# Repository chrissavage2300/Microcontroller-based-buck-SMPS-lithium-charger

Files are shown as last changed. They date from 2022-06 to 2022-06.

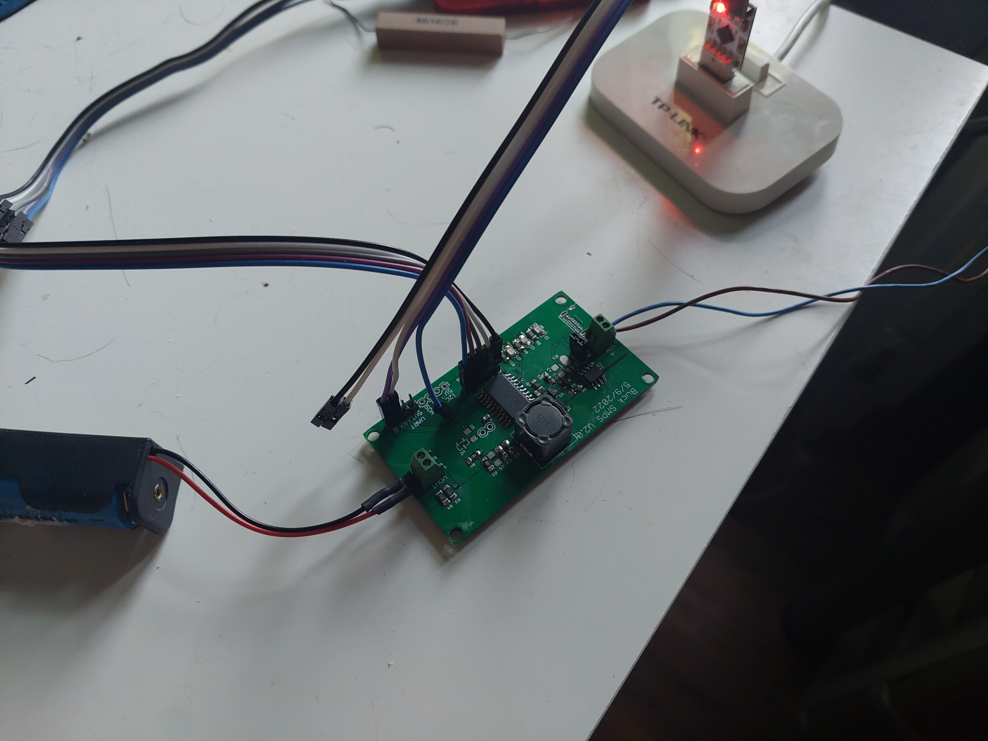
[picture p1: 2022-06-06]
20220605_084859.jpg

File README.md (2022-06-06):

# Microcontroller-based-buck-SMPS-lithium-charger
PIC18F13K22 Based lithium buck coverter

Based on app note SLAA-287-Li-Ion Battery Charger Solution Using an MSP430™ MCU from Texas Instruments. 

Note: U2, JP3 and R5 are not used. The internal VREF is used.

JP6/7 have been replaced with 1206 LEDs

R6-50ohms may work rather than 0.

JP5 limits the input voltage to 5V, so IC1 wouldnt need to be populated in this case. It therefore may also work off of a USB-C connector but this hasnt been tested. 

Pins RC1 and RC2 are not used even though they are called out.

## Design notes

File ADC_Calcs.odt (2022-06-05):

10 BIT ADC
0 to 1024

Voltage Reference | V/Step
5.00 | 4.883mV
2.048 | 2.00mV

Voltage | VDR (R1 = 3k, R2=2k) | Counts (2.048VREF)
4.20V | 1.68V | 840
4.00 | 1.60 | 800
3.30V | 1.32V | 660
3.00V | 1.20V | 600
2.80V | 1.12 | 560

Current Calculations (1:1)

Current (A) | Voltage (V) | Counts (2.048 Vref)
1.2 | 1.2V | 600
1.0 | 1V | 500
0.5 | 500mV | 250
0.25 | 250mV | 125
0.1 | 100mV | 50
0.01 | 10mV | 5

4.954V/10ohms = 495mA, adc 252

4.035V/4.1 ohms = 4.035VDC, IVB=0.984V, SP = 530

4.108V/4.1ohms=1A, IVB = 1.00VDC, SP = 540

ADC = 753, VFB=1.500VDC, Lithium voltage = 3.771 measured.

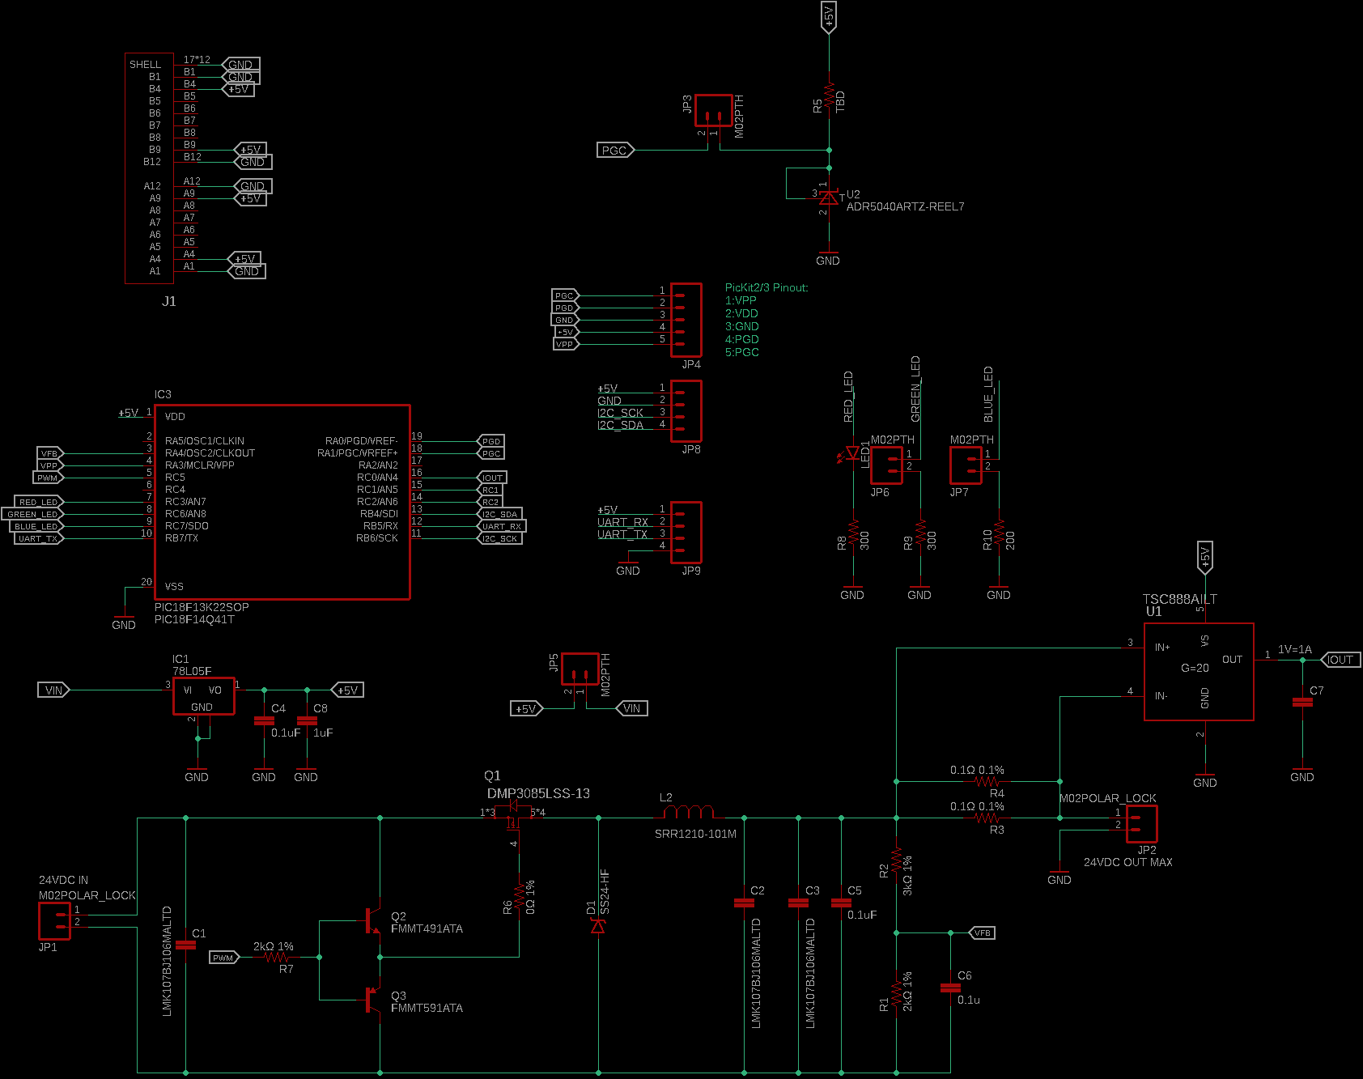
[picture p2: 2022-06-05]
Buck_SMPS_Rev2_2022_05_26_A.png

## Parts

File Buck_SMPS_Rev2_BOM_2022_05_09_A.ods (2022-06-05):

Part | Value | Device | Package | Description
C1 | LMK107BJ106MALTD | CAP1206 | 1206 | Capacitor | 587-2562-1-ND (https://www.digikey.com/en/products/detail/taiyo-yuden/LMK107BJ106MALTD/2269341)
C2 | LMK107BJ106MALTD | CAP1206 | 1206 | Capacitor | 587-2562-1-ND (https://www.digikey.com/en/products/detail/taiyo-yuden/LMK107BJ106MALTD/2269341)
C3 | LMK107BJ106MALTD | CAP1206 | 1206 | Capacitor | 587-2562-1-ND (https://www.digikey.com/en/products/detail/taiyo-yuden/LMK107BJ106MALTD/2269341)
C4 | 0.1uF | CAP1206 | 1206 | Capacitor | 1276-1017-1-ND/stock
C5 | 0.1uF | CAP1206 | 1206 | Capacitor | 1276-1017-1-ND/stock
C6 | 0.1u | CAP0805 | 805 | Capacitor | 478-10836-1-ND
C7 | 0.1u | CAP0805 | 805 | Capacitor | 478-10836-1-ND
C8 | 1uF | CAP1206 | 1206 | Capacitor | optional
D1 | SS24-HF | DIODE-SCHOTTKY-MBRA140 | SMA-DIODE | Schottky diodes in SFE's production catalog | 641-SS24-HFCT-ND/stock
IC1 | 78L05F | 78L05F | SOT89 | POSITOIV-VOLTAGE REGULATORS | MC78L05ACHT1GOSCT-ND/STOCK
IC3 | PIC18F13K22SOP | PIC18F13K22SOP | SOP20W | 18/20/28-Pin High-Performance, Enhanced Flash Microcontrollers | PIC18F14Q41T-I/SO
J1 | USB4085-GF-A | USB4085-GF-A | CONN16_USB4085-GF-A_GCT |  | 2073-USB4085-GF-ACT-ND
JP1 | M02POLAR_LOCK | M02POLAR_LOCK | MOLEX-1X2_LOCK | Standard 2-pin 0.1
JP2 | M02POLAR_LOCK | M02POLAR_LOCK | MOLEX-1X2_LOCK | Standard 2-pin 0.1
JP3 | M02PTH | M02PTH | 1X02 | Standard 2-pin 0.1
JP4 |  | M05PTH_LONGPADS | 1X05_LONGPADS | Header 5
JP5 | M02PTH | M02PTH | 1X02 | Standard 2-pin 0.1
JP6 | M02PTH | M02PTH | 1X02 | Standard 2-pin 0.1
JP7 | M02PTH | M02PTH | 1X02 | Standard 2-pin 0.1
JP8 |  | M04LOCK | 1X04_LOCK | Header 4
JP9 |  | M04LOCK | 1X04_LOCK | Header 4
L2 | SRR1210-101M | SRR1210-680M | IND_BOURNS_SRR1210 |  | SRR1210-101MCT-ND
LED1 |  | LED1206 | LED-1206 | LEDs | stock
Q1 | DMP3085LSS-13 | DMP3085LSS-13IC_DMP3085LSS-13_DIO-M | IC_DMP3085LSS-13_DIO-M |  | DMP3085LSS-13DICT-ND
Q2 | FMMT491ATA | TRANSISTOR_NPNMMBT5088 | SOT23 | Generic NPN BJT | stock
Q3 | FMMT591ATA | TRANSISTOR_PNPMMBT4403 | SOT23 | Generic PNP BJT | stock
R1 | 2kΩ 0.1% | RESISTOR1206 | 1206 | Resistor | stock
R2 | 21.50kΩ 0.1% | RESISTOR1206 | 1206 | Resistor
R3 | 0.1Ω 0.1% | RESISTOR1206 | 1206 | Resistor | 273-KDV12FR100ETCT-ND (https://www.digikey.com/en/products/detail/ohmite/KDV12FR100ET/10476508)
R4 | 0.1Ω 0.1% | RESISTOR1206 | 1206 | Resistor | 273-KDV12FR100ETCT-ND (https://www.digikey.com/en/products/detail/ohmite/KDV12FR100ET/10476508)
R5 | TBD | RESISTOR1206 | 1206 | Resistor
R6 | 50Ω 1% | RESISTOR1206 | 1206 | Resistor | 13-RC1206FR-1347RLCT-ND (https://www.digikey.com/en/products/detail/yageo/RC1206FR-1347RL/14286687)
R7 | 2kΩ 1% | RESISTOR1206 | 1206 | Resistor | stock
R8 | 300 | RESISTOR1206 | 1206 | Resistor
R9 | 300 | RESISTOR1206 | 1206 | Resistor
R10 | 200 | RESISTOR1206 | 1206 | Resistor
U1 | TSC888AILT | INA180A1IDBVR | DBV0005A_N |  | stock
U2 | ADR5040ARTZ-REEL7 | ADR5040ARTZ-REEL7 | RT_3_ADI |  | Stock-may not usre

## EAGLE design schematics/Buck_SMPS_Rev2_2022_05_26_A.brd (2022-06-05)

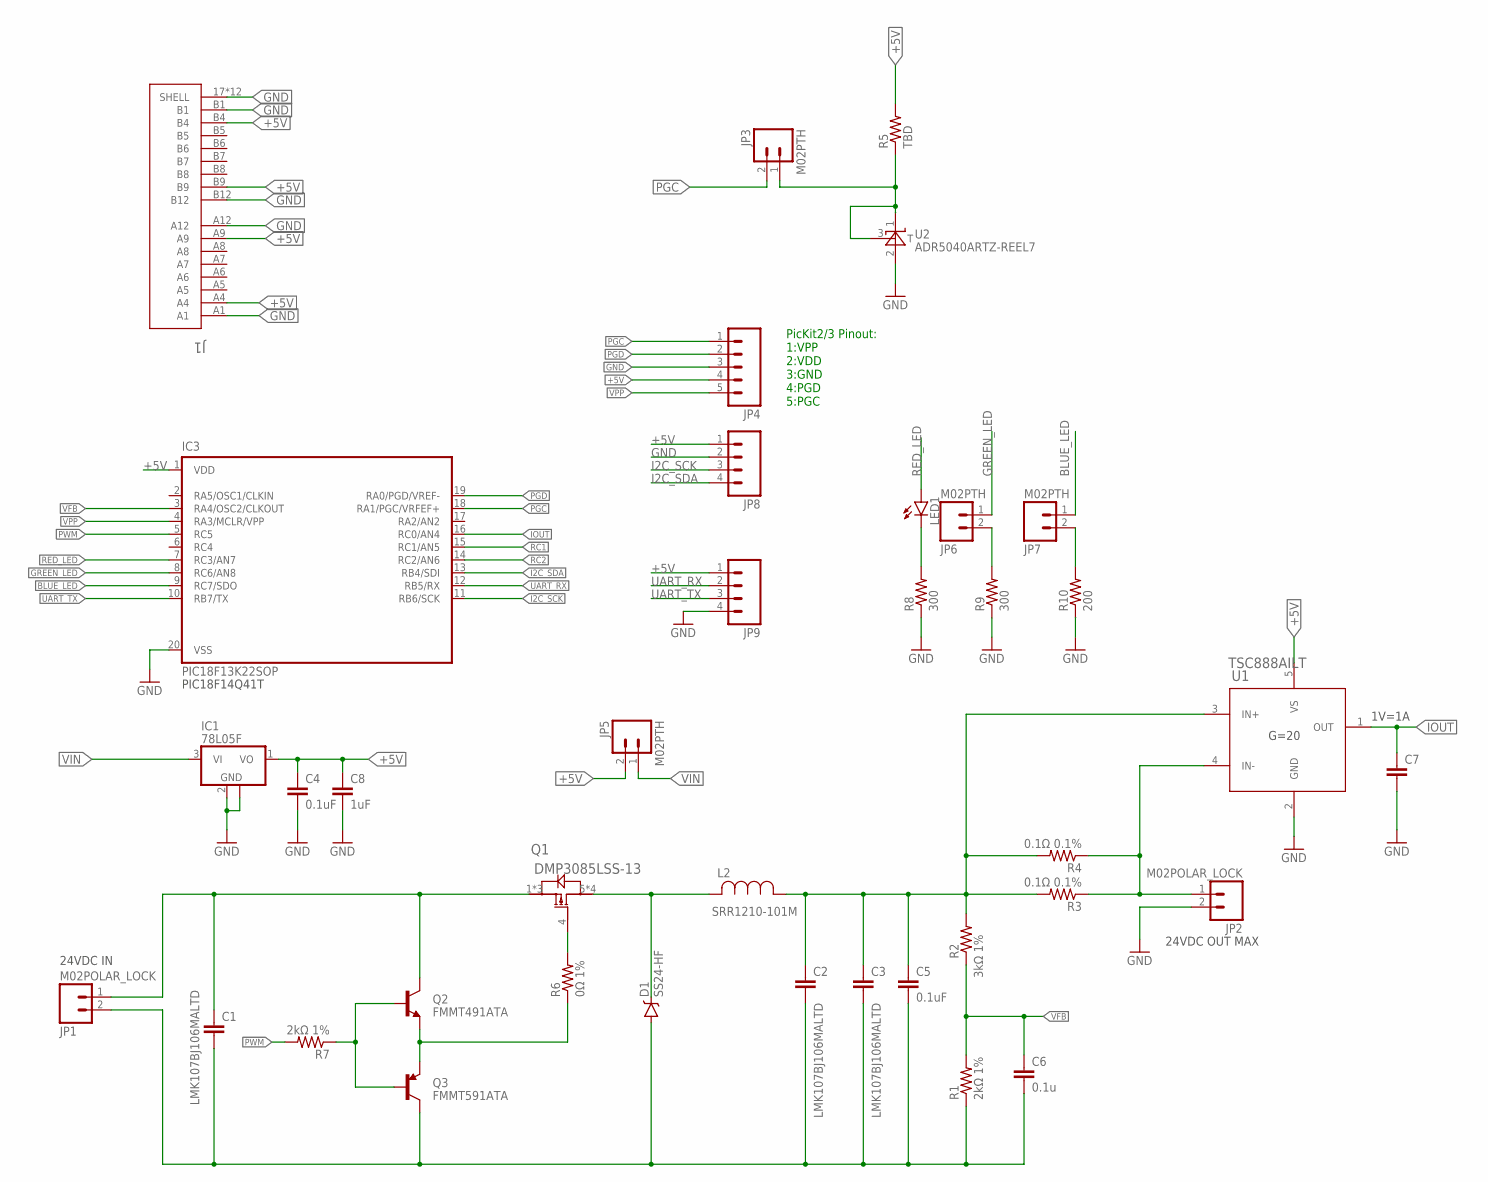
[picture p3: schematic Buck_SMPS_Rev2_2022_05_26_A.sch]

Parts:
C1, C2, C3: LMK107BJ106MALTD; 1206
C4, C5: 0.1uF; 1206
C6: 0.1u; 0805
C7: CAP0805; 0805
C8: 1uF; 1206
D1: SS24-HF; SMA-DIODE
IC1: 78L05F; SOT89
IC3: PIC18F13K22SOP; SOP20W
J1: USB4085-GF-A; CONN16_USB4085-GF-A_GCT
JP1, JP2: M02POLAR_LOCK; MOLEX-1X2_LOCK
JP3, JP5, JP6, JP7: M02PTH; 1X02
JP4: M05PTH_LONGPADS; 1X05_LONGPADS
JP8, JP9: M04LOCK; 1X04_LOCK
L2: SRR1210-101M; IND_BOURNS_SRR1210
LED1: LED1206; LED-1206
Q1: DMP3085LSS-13; IC_DMP3085LSS-13_DIO-M
Q2: FMMT491ATA; SOT23
Q3: FMMT591ATA; SOT23
R1, R7: 2kΩ 1%; 1206
R2: 3kΩ 1%; 1206
R3, R4: 0.1Ω 0.1%; 1206
R5: TBD; 1206
R6: 0Ω 1%; 1206
R8, R9: 300; 1206
R10: 200; 1206
U1: TSC888AILT; DBV0005A_N
U2: ADR5040ARTZ-REEL7; RT_3_ADI

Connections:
+5V: C4.1, C8.1, IC1.1 (VO), IC3.1 (VDD), J1.A4, J1.A9, J1.B4, J1.B9, JP4.4, JP5.2, JP8.1, JP9.1, R5.2, U1.5 (VS)
BLUE_LED: IC3.9 (RC7/SDO), JP7.1
GND: C1.2, C2.2, C3.2, C4.2, C5.2, C6.2, C7.2, C8.2, D1.A, IC1.2 (GND), IC1.2@1 (GND), IC3.20 (VSS), J1.17 (SHELL), J1.18 (SHELL), J1.19 (SHELL), J1.20 (SHELL), J1.21 (SHELL), J1.22 (SHELL), J1.23 (SHELL), J1.24 (SHELL), J1.25 (SHELL), J1.26 (SHELL), J1.27 (SHELL), J1.28 (SHELL), J1.A1, J1.A12, J1.B1, J1.B12, JP1.2, JP2.2, JP4.3, JP8.2, JP9.4, Q3.3 (C), R1.1, R8.1, R9.1, R10.1, U1.2 (GND), U2.2 (A)
GREEN_LED: IC3.8 (RC6/AN8), JP6.1
I2C_SCK: IC3.11 (RB6/SCK), JP8.3
I2C_SDA: IC3.13 (RB4/SDI), JP8.4
IOUT: C7.1, IC3.16 (RC0/AN4), U1.1 (OUT)
unnamed: LED1.C, R8.2
unnamed: Q2.2 (E), Q3.2 (E), R6.1
unnamed: JP6.2, R9.2
unnamed: JP7.2, R10.2
unnamed: Q1.4 (G), R6.2
unnamed: Q2.1 (B), Q3.1 (B), R7.1
PGC: IC3.18 (RA1/PGC/VRFEF+), JP3.2, JP4.1
PGD: IC3.19 (RA0/PGD/VREF-), JP4.2
PWM: IC3.5 (RC5), R7.2
RC1: IC3.15 (RC1/AN5)
RC2: IC3.14 (RC2/AN6)
RED_LED: IC3.7 (RC3/AN7), LED1.A
SW: D1.C, L2.2, Q1.5 (D), Q1.6 (D), Q1.7 (D), Q1.8 (D)
UART_RX: IC3.12 (RB5/RX), JP9.2
UART_TX: IC3.10 (RB7/TX), JP9.3
VFB: C6.1, IC3.3 (RA4/OSC2/CLKOUT), R1.2, R2.1
VIN: C1.1, IC1.3 (VI), JP1.1, JP5.1, Q1.1 (S), Q1.2 (S), Q1.3 (S), Q2.3 (C)
VOUT: C2.1, C3.1, C5.1, L2.1, R2.2, R3.2, R4.2, U1.3 (IN+)
VOUT+: JP2.1, R3.1, R4.1, U1.4 (IN-)
VPP: IC3.4 (RA3/MCLR/VPP), JP4.5
VREF+: JP3.1, R5.1, U2.1 (C), U2.3 (T)

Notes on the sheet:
PicKit2/3 Pinout: 1:VPP 2:VDD 3:GND 4:PGD 5:PGC
24VDC IN
24VDC OUT MAX
G=20
1V=1A
PIC18F14Q41T

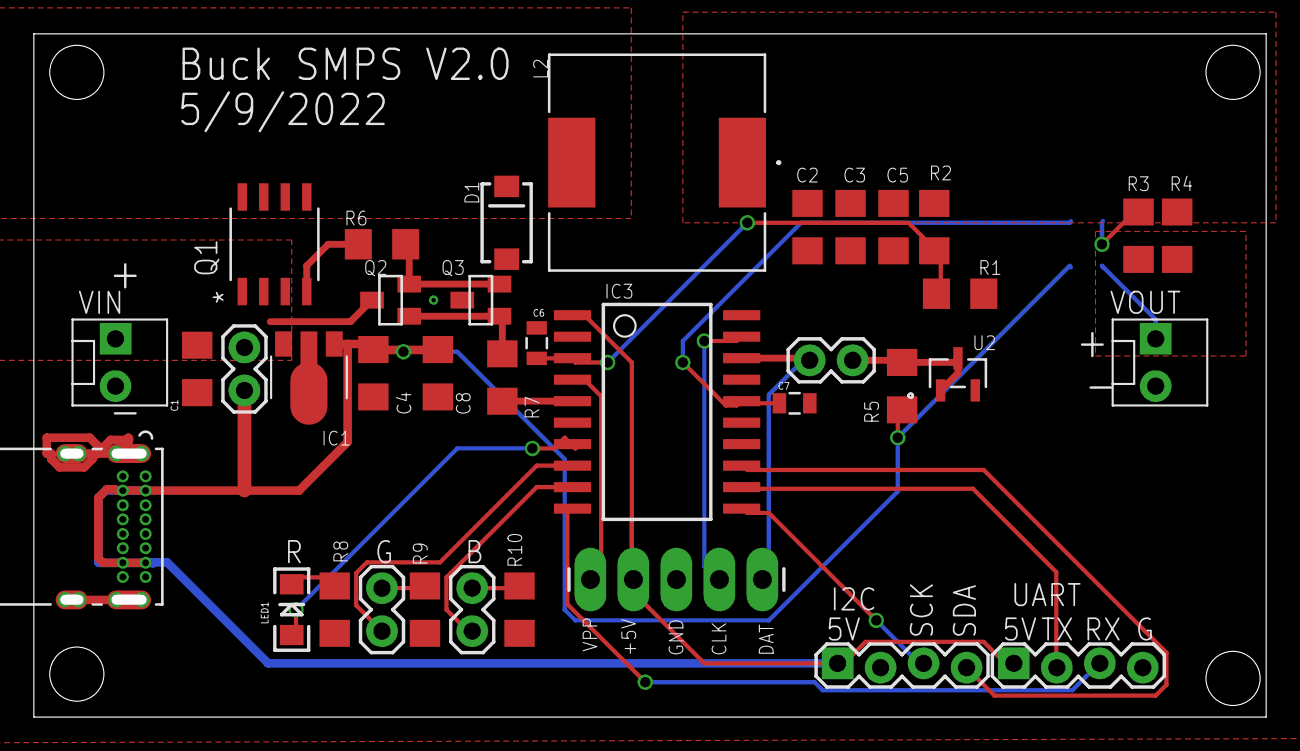
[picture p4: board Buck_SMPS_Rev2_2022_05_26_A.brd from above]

Board: 2 copper layers, 72.8 x 40.4 mm, 38 parts (1 on the bottom side), 26 nets.

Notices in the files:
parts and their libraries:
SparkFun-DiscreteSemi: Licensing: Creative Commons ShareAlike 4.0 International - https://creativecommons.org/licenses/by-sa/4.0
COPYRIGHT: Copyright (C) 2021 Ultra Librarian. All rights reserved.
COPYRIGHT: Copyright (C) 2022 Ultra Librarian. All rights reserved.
